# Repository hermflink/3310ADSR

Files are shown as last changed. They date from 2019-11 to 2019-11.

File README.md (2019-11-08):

# 3310ADSR
Dual ADSR based on AS3310

Kicad project files of a dual ADSR based on two AS3310 components. Part of a modular DIY synth project, other modules are available in other repositories. Likely compatible with a CEM3310.

Used the Audio.lib from https://kicad.github.io/symbols/Audio to extend the Kicad library for the AS3310 component.

Designed to work with +/- 15V, not tested for +/- 12V

The PCB is 9.5 x 5.5 cm and has no PCB-mounting of potmeters, switches, jacks; these are all connected by pin header connectors

Important note: Gate must never be unconnected, so must be either GND (off) or 2.6 to 15V (on), otherwise release will never occur. Applying a negative voltage to the gate will break your AS3310!!!

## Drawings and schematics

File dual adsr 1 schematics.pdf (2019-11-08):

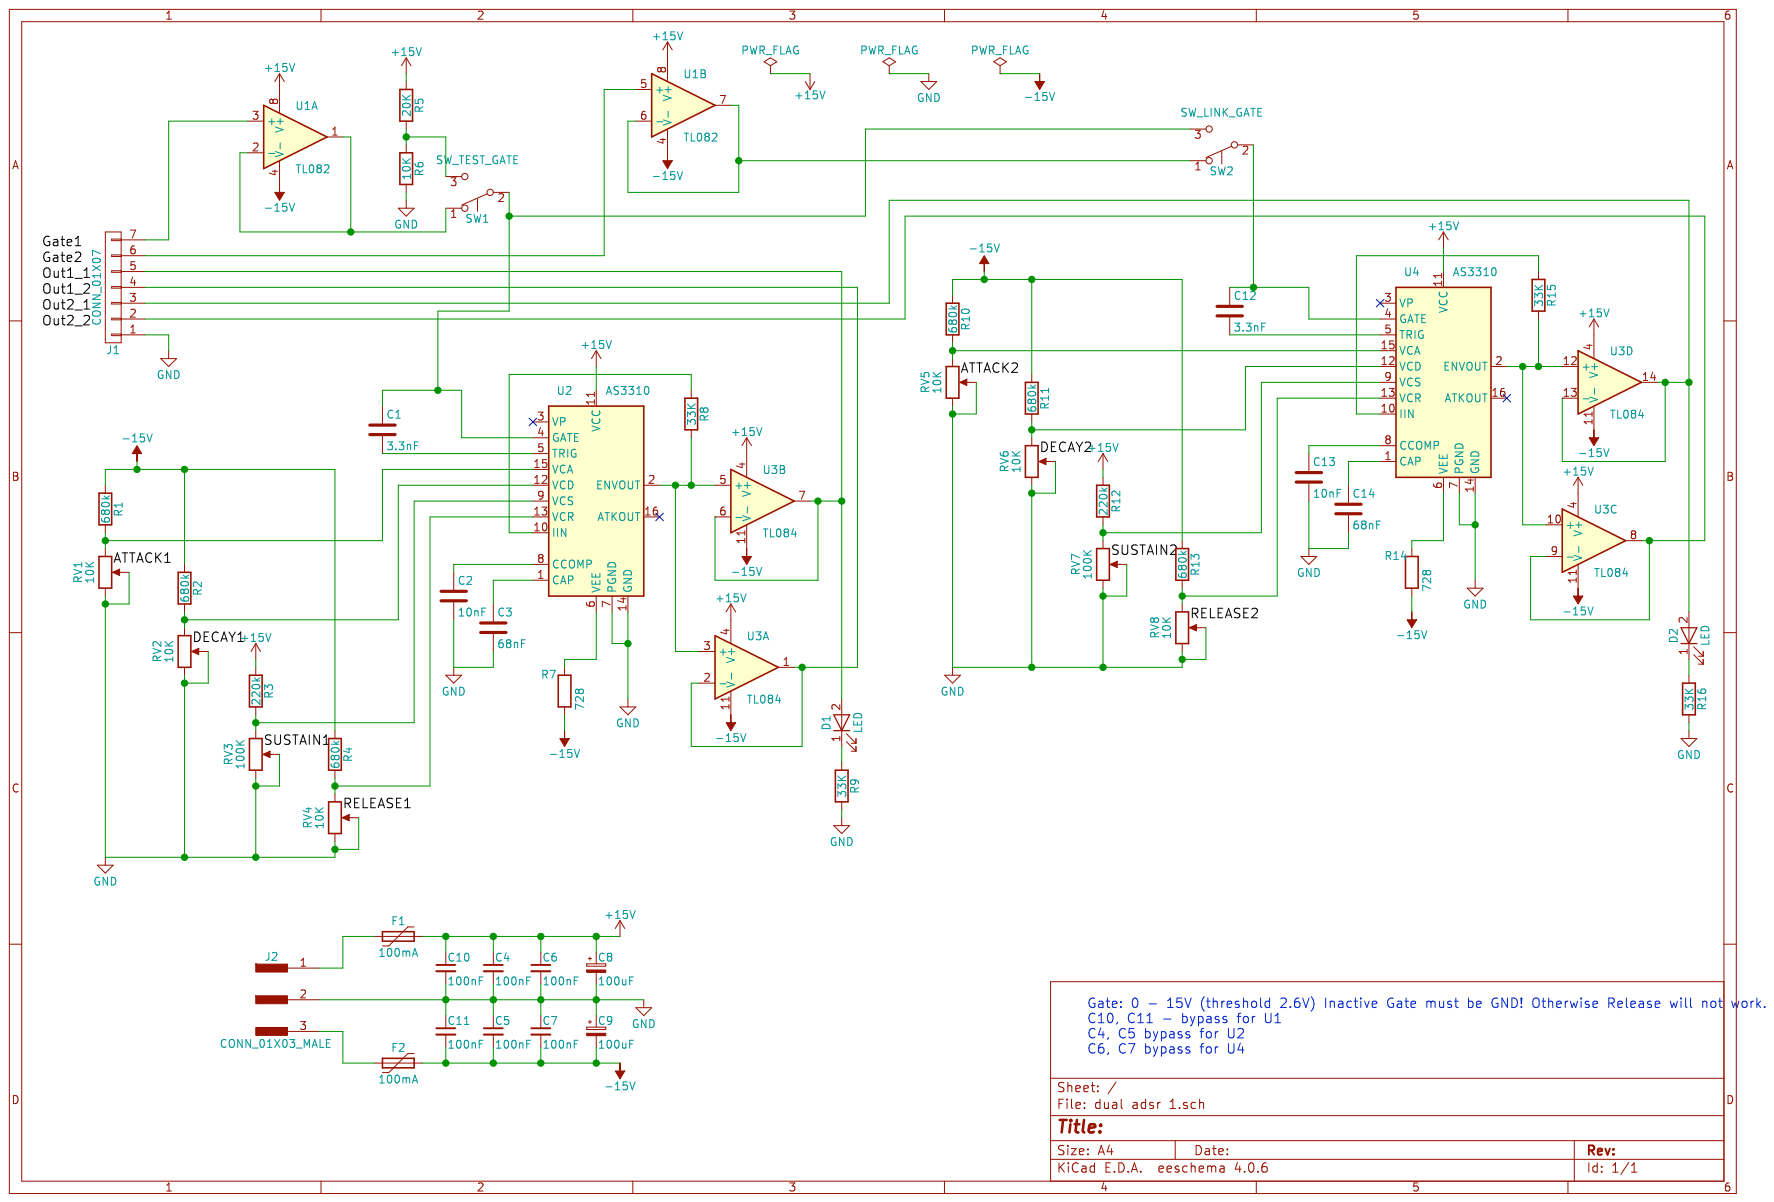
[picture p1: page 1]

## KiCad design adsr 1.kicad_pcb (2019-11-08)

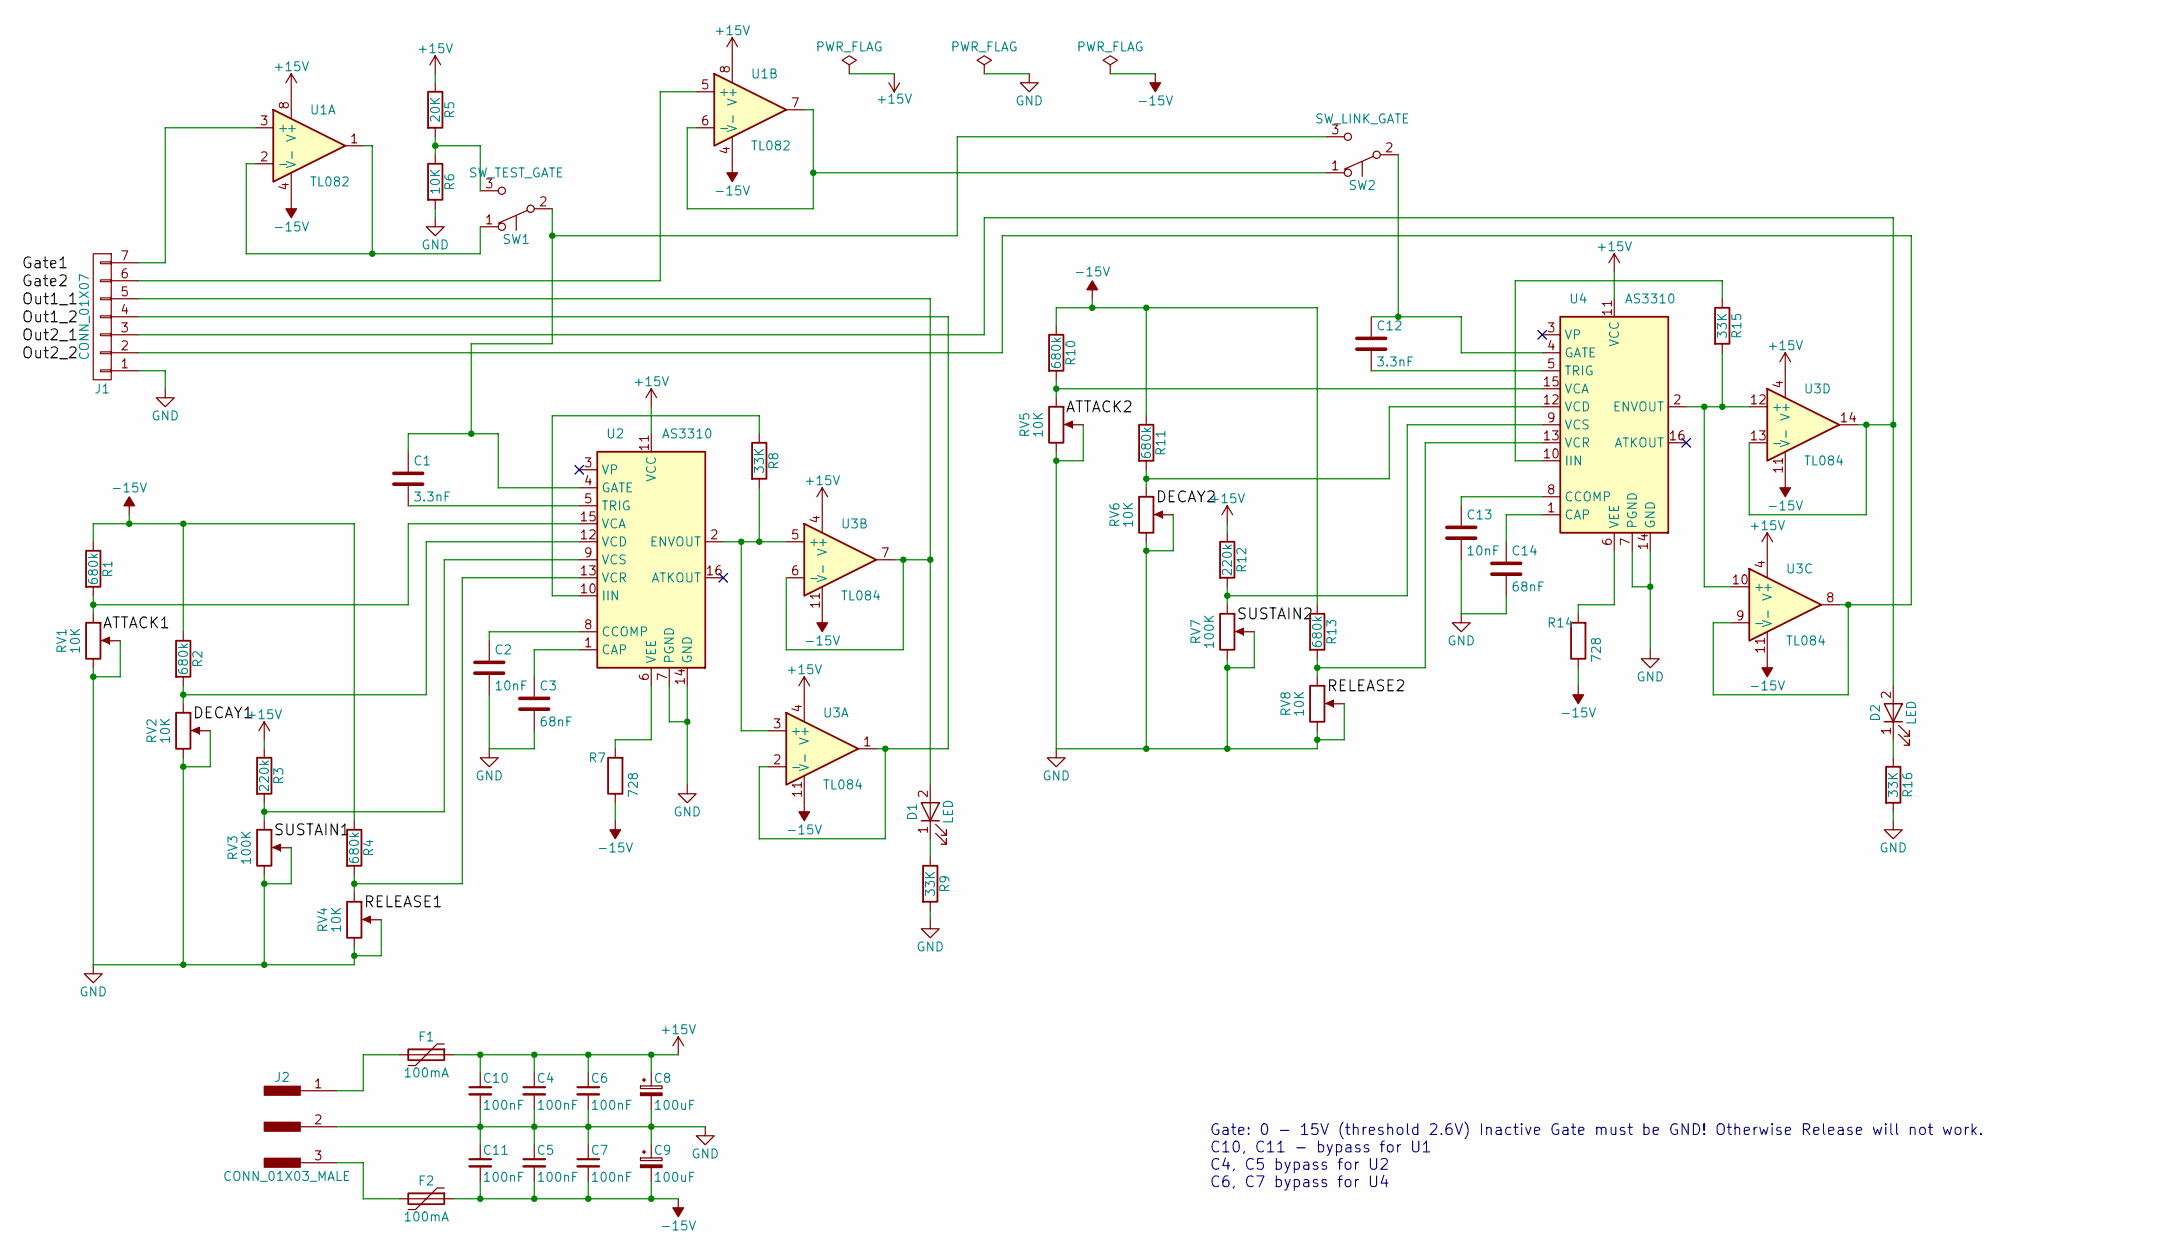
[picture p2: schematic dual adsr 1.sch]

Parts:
C1, C12: 3.3nF; C_Disc_D4.3mm_W1.9mm_P5.00mm
C2, C13: 10nF; C_Disc_D4.3mm_W1.9mm_P5.00mm
C3, C14: 68nF; C_Disc_D4.3mm_W1.9mm_P5.00mm
C4, C5, C6, C7, C10, C11: 100nF; C_Disc_D5.0mm_W2.5mm_P5.00mm
C8, C9: 100uF; CP_Radial_D8.0mm_P2.50mm
D1, D2: LED; Pin_Header_Straight_1x02_Pitch2.54mm
F1, F2: 100mA; C_Disc_D6.0mm_W2.5mm_P5.00mm
J1: CONN_01X07; Pin_Header_Straight_1x07_Pitch2.54mm
J2: CONN_01X03_MALE; Pin_Header_Straight_1x03_Pitch2.54mm
R1, R2, R4, R10, R11, R13: 680k; R_Axial_DIN0207_L6.3mm_D2.5mm_P2.54mm_Vertical
R3, R12: 220k; R_Axial_DIN0207_L6.3mm_D2.5mm_P2.54mm_Vertical
R5: 20K; R_Axial_DIN0207_L6.3mm_D2.5mm_P2.54mm_Vertical
R6: 10K; R_Axial_DIN0207_L6.3mm_D2.5mm_P2.54mm_Vertical
R7, R14: 728; R_Axial_DIN0207_L6.3mm_D2.5mm_P2.54mm_Vertical
R8, R9, R15, R16: 33K; R_Axial_DIN0207_L6.3mm_D2.5mm_P2.54mm_Vertical
RV1, RV2, RV4, RV5, RV6, RV8: 10K; Pin_Header_Straight_1x03_Pitch2.54mm
RV3, RV7: 100K; Pin_Header_Straight_1x03_Pitch2.54mm
SW1: SW_TEST_GATE; Pin_Header_Straight_1x03_Pitch2.54mm
SW2: SW_LINK_GATE; Pin_Header_Straight_1x03_Pitch2.54mm
U1: TL082; DIP-8_W7.62mm
U2, U4: AS3310; DIP-16_W7.62mm
U3: TL084; DIP-14_W7.62mm

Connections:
+15V: C4.1, C6.1, C8.1, C10.1, F1.1, R3.1, R5.1, R12.1, U1.8 (V+), U2.11 (VCC), U3.4 (V+), U4.11 (VCC)
-15V: C5.2, C7.2, C9.2, C11.2, F2.1, R1.1, R2.1, R4.1, R7.1, R10.1, R11.1, R13.1, R14.1, U1.4 (V-), U3.11 (V-)
GND: C2.2, C3.2, C4.2, C5.1, C6.2, C7.1, C8.2, C9.1, C10.2, C11.1, C13.2, C14.2, J1.1, J2.2, R6.2, R9.2, R16.2, RV1.2, RV1.3, RV2.2, RV2.3, RV3.2, RV3.3, RV4.2, RV4.3, RV5.2, RV5.3, RV6.2, RV6.3, RV7.2, RV7.3, RV8.2, RV8.3, U2.7 (PGND), U2.14 (GND), U4.7 (PGND), U4.14 (GND)
unnamed: C1.1, SW1.2 (B), SW2.3 (C), U2.4 (GATE)
unnamed: C1.2, U2.5 (TRIG)
unnamed: C2.1, U2.8 (CCOMP)
unnamed: C3.1, U2.1 (CAP)
unnamed: C12.1, SW2.2 (B), U4.4 (GATE)
unnamed: C12.2, U4.5 (TRIG)
unnamed: C13.1, U4.8 (CCOMP)
unnamed: C14.1, U4.1 (CAP)
unnamed: D1.1 (K), R9.1
unnamed: D1.2 (A), J1.5, U3.6 (-), U3.7
unnamed: D2.1 (K), R16.1
unnamed: D2.2 (A), J1.3, U3.13 (-), U3.14
unnamed: F1.2, J2.1
unnamed: F2.2, J2.3
unnamed: J1.2, U3.8, U3.9 (-)
unnamed: J1.4, U3.1, U3.2 (-)
unnamed: J1.6, U1.5 (+)
unnamed: J1.7, U1.3 (+)
unnamed: R1.2, RV1.1, U2.15 (VCA)
unnamed: R2.2, RV2.1, U2.12 (VCD)
unnamed: R3.2, RV3.1, U2.9 (VCS)
unnamed: R4.2, RV4.1, U2.13 (VCR)
unnamed: R5.2, R6.1, SW1.3 (C)
unnamed: R7.2, U2.6 (VEE)
unnamed: R8.1, U2.10 (IIN)
unnamed: R8.2, U2.2 (ENVOUT), U3.3 (+), U3.5 (+)
unnamed: R10.2, RV5.1, U4.15 (VCA)
unnamed: R11.2, RV6.1, U4.12 (VCD)
unnamed: R12.2, RV7.1, U4.9 (VCS)
unnamed: R13.2, RV8.1, U4.13 (VCR)
unnamed: R14.2, U4.6 (VEE)
unnamed: R15.1, U4.10 (IIN)
unnamed: R15.2, U3.10 (+), U3.12 (+), U4.2 (ENVOUT)
unnamed: SW1.1 (A), U1.1, U1.2 (-)
unnamed: SW2.1 (A), U1.6 (-), U1.7

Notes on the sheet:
Gate: 0 - 15V (threshold 2.6V) Inactive Gate must be GND! Otherwise Release will not work. C10, C11 - bypass for U1 C4, C5 bypass for U2 C6, C7 bypass for U4

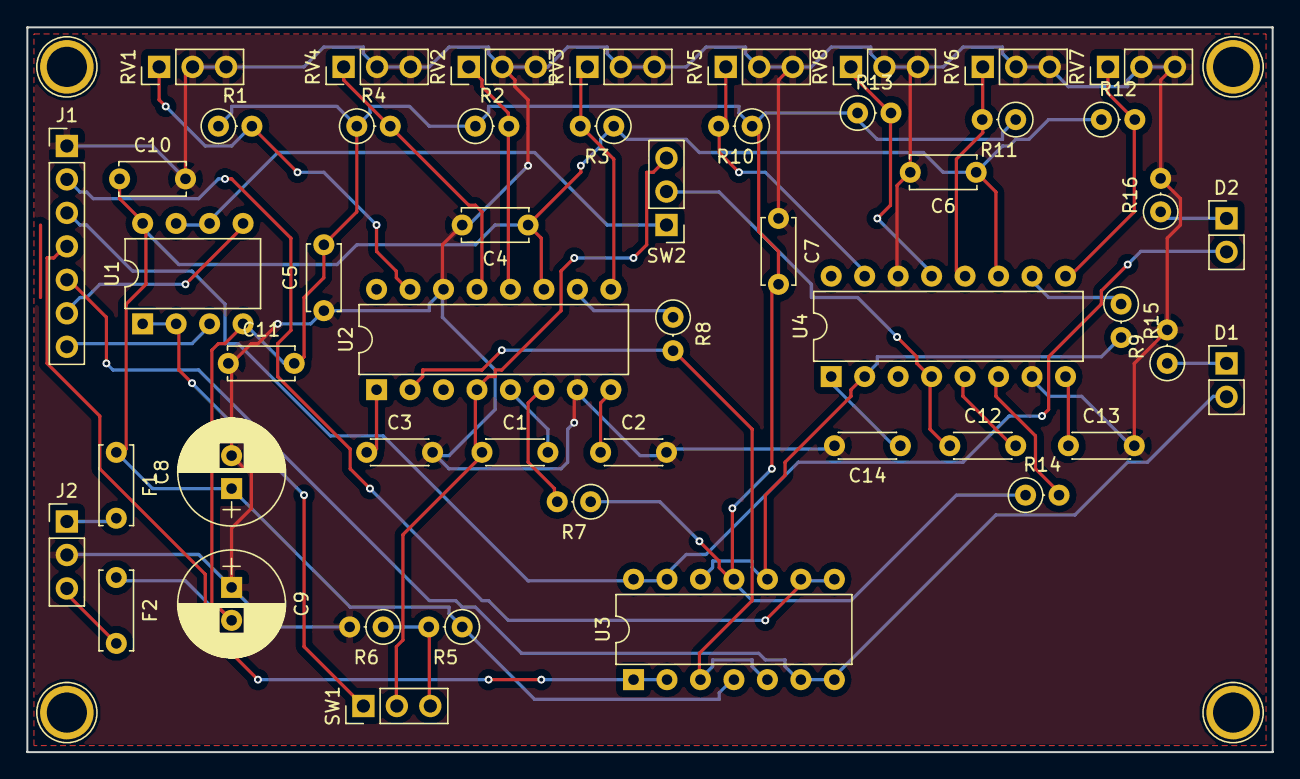
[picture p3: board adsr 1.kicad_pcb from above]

Board: 2 copper layers, 94.5 x 55.0 mm, 50 parts (0 on the bottom side), 38 nets.
